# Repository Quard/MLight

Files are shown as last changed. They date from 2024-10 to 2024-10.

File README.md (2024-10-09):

# MLight

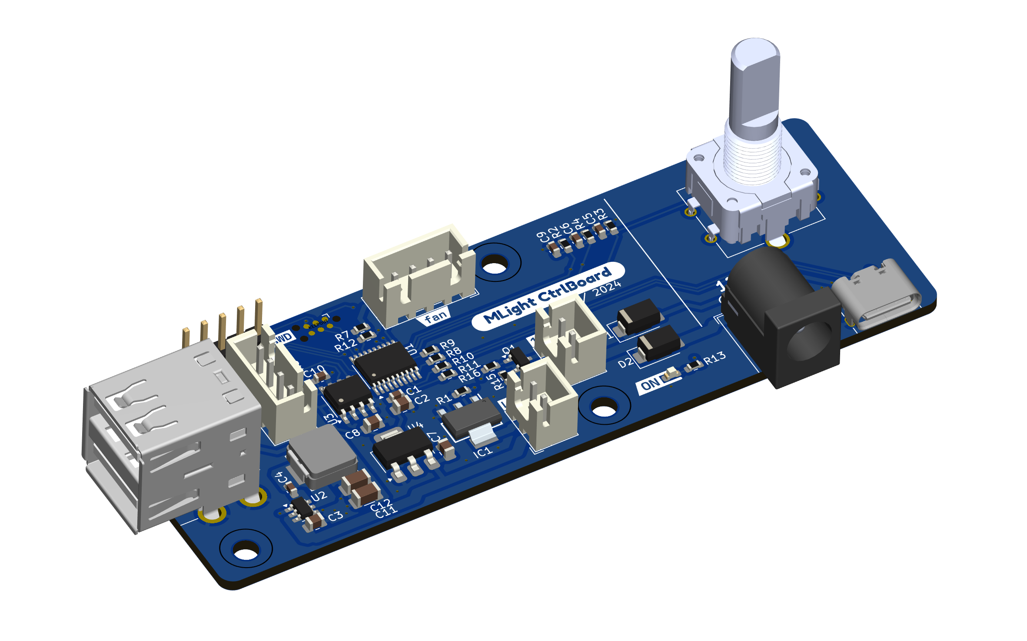
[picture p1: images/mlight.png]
MLight Control Board


MLight is a compact, all-in-one control board designed to manage auxiliary tools for soldering equipment. It was primarily developed for an affordable Chinese digital microscope, aiming to reduce the number of power cords and to integrate lighting for the microscope. Additionally, it can control the fan of a basic DIY fume extractor, built using a PC fan and an aquarium coal filter, and provide power to a small external HDMI display for the microscope.

Features of the Control Board:

* Capable of being powered by an external DC 12V source or a QuickChange USB source.
* Bypasses power to the microscope only when the voltage is at 12V.
* Custom ring light with PWM (Pulse Width Modulation) brightness control.
* The PWM for the light is configurable at frequencies of 1 kHz, 4 kHz, 8 kHz, or 16 kHz to prevent image distortion from the microscope.
* Provides a 12V output for PC fan with PWM speed control support for the DIY fume extractor.
* Features a USB output of 1.5A for powering an external HDMI display.
* Includes an OLED display and encoder for easy control.
* Equipped with external EEPROM memory for storing and restoring settings.

[A brief demonstration video of the system in operation.](https://youtube.com/shorts/ih5DoEOJhLI)

## Controls

| Action | Description |
|---|---|
| Encoder short press | Switch between fan and light |
| Encoder rotate | Change the value of current selected element |
| Encoder long press | Disable/enable fan and light |
| Encoder rotate pressed | Change the light PWM frequency |

## Project parts

### Firmware

The `firmware` folder includes an STM32CubeIDE CMake project, with all source code developed using CMSIS.

### Control Board

The KiCad project is located in the `hardware/control_board` directory. It includes a BOM file in the project root and an interactive BOM (iBOM) in the `bom` folder to facilitate assembly.

### Ring Light

The same structure applies to the Ring Light project, with its root located in the `hardware/ring_light` directory. It also contains a BOM file in the project root and an interactive BOM (iBOM) in the `bom` folder to assist with assembly.

### 3d

The `3d` folder contains STL files and Fusion 360 source files for the brackets used to mount the control board and ring light onto a microscope stand.

## Display elements

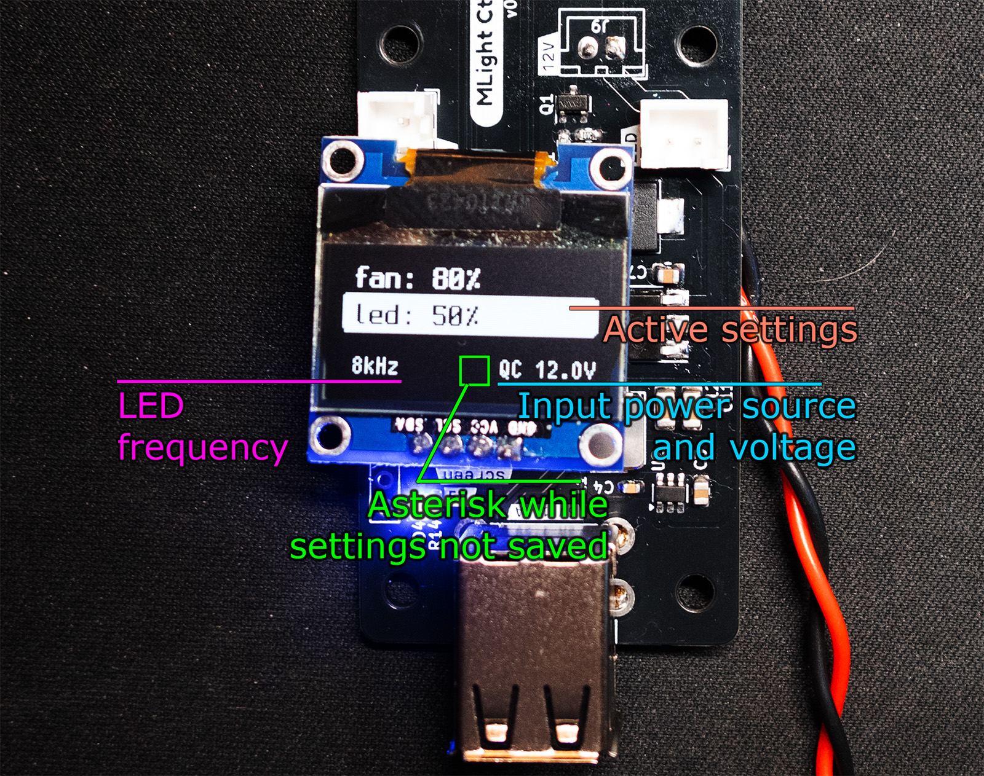
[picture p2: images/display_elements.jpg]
MLight Control board - display elements


## Components block diagram

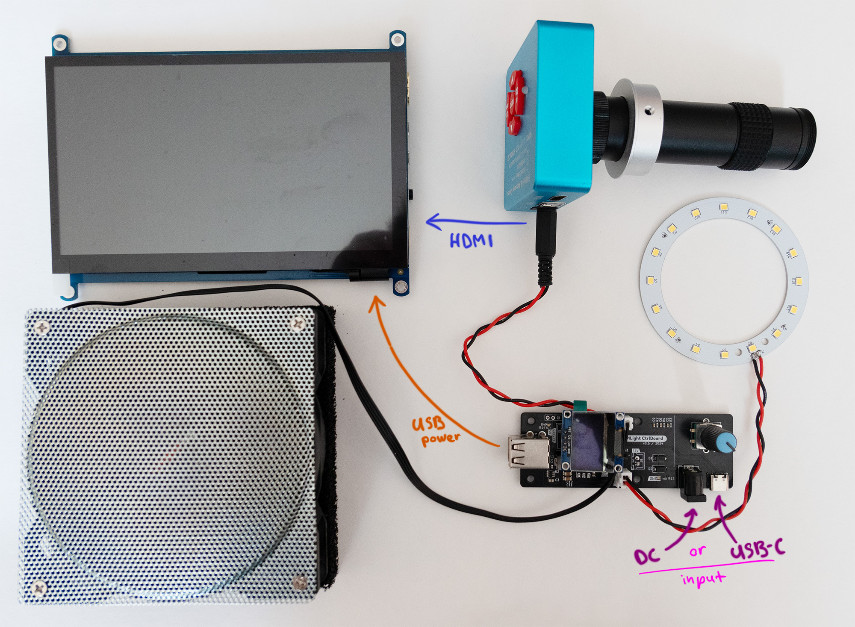
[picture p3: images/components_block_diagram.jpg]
MLight components block diagram


## BOM

### Control Board

|Reference|Value|Qty|Manufacturer Part Number|LCSC|MOUSER|
|---|-----|---|---|----|---|
|C1,C4,C10|100nF|3|CL10B104KB8NNNC|C1591|187-CL10B104KB8NNNC |
|C2|4.7uF|1|CL21A475KAQNNNE|C1779|187-CL21A475KAQNNNE |
|C3,C7,C8|10uF|3|CL21A106KOQNNNE|C1713|187-CL21A106KOQNNNE |
|C5,C6,C9|10nF|3|CL10B103JB8NNNC|C7248|187-CL10B103JB8NNNC |
|C11,C12|22uF|2|CL31A226KAHNNNE|C12891|187-CL31A226KAHNNNE |
|D1,D2|B340|2|B340A-13-F|C85098|621-B340A-F|
|D3|LED|1|150060BS75000|C84266|710-150060BS75000|
|D4|LED|1|150060RS75000|C84263|710-150060RS75000|
|IC1|FZT1049ATA|1|FZT1049ATA|C73835|522-FZT1049ATA|
|J1|USB_A_Stacked|1| 67298-4090|C908455|538-67298-4090|
|J3|Light|1||C158012||
|J4|Fan|1|47053-3000|C19795120|538-47053-3000|
|J5|OLED SSD1306|1||||
|J7|USB_C_Receptacle_USB2.0|1|GSB1C211110DS1HR|C709357|523-GSB1C211110DS1HR|
|J8|Barrel_Jack|1|KLDHCX-0202-BP-LT|C720558|806-KLDHCX0202BPLT|
|J9|Conn_01x02|1||C158012||
|L1|4.7uH|1|IHLP2525CZER4R7M01|C553961|70-IHLP2525CZER4R7M1|
|Q1|AO3400A|1|AO3400A|C20917|942-IRLML6344TRPBF|
|R1,R2,R3,R4,R5,R6,R8,R10,R15|10k|9|RC0603FR-0710KL|C98220|603-RC0603FR-0710KL|
|R7|180k|1|RC0603FR-07180KL|C123419|603-RC0603FR-07180KL|
|R9,R11|2.2k|2|RC0603FR-072K2L|C114662|603-RC0603FR-072K2L|
|R12|33k|1|RC0603FR-0733KL|C126359|603-RC0603FR-0733KL|
|R13,R16|1k|2|RC0603FR-071KL|C22548|603-RC0603FR-071KL|
|R14|1.8k|1|RC0603FR-071K8L|C185354|603-RC0603FR-071K8L|
|SW4|RotaryEncoder_Switch|1|C18164805|652-PEC12R-4220F-S24|PEC12R-4220F-S0024|
|U1|STM32G030F6Px|1|STM32G030F6P6TR|C529330|511-STM32G030F6P6TR|
|U2|AP63205WU|1|AP63205WU-7|C2071056|621-AP63205WU-7|
|U3|M24C02-WMN|1|M24C02-RMN6TP|C83836|511-M24C02-RMN6TP|
|U4|NCP1117-3.3_SOT223|1|NCP1117ST33T3G|C26537|863-NCP1117ST33T3G|

### Ring Light

|Reference|Value|Qty|Manufacturer Part Number|LCSC|MOUSER|
|---|-----|---|---|----|---|
|D1,D2,D3,D4,D5,D6,D7,D8,D9,D10,D11,D12,D13,D14,D15,D16|LED|16|JE2835AWT-R-H40EA0000-N0000001|C5220767|941-JE2835AWTH40EAN|
|R1,R2,R3,R4|0|4|RC0603JR-070RL|C95177|603-RC0603JR-070RL|

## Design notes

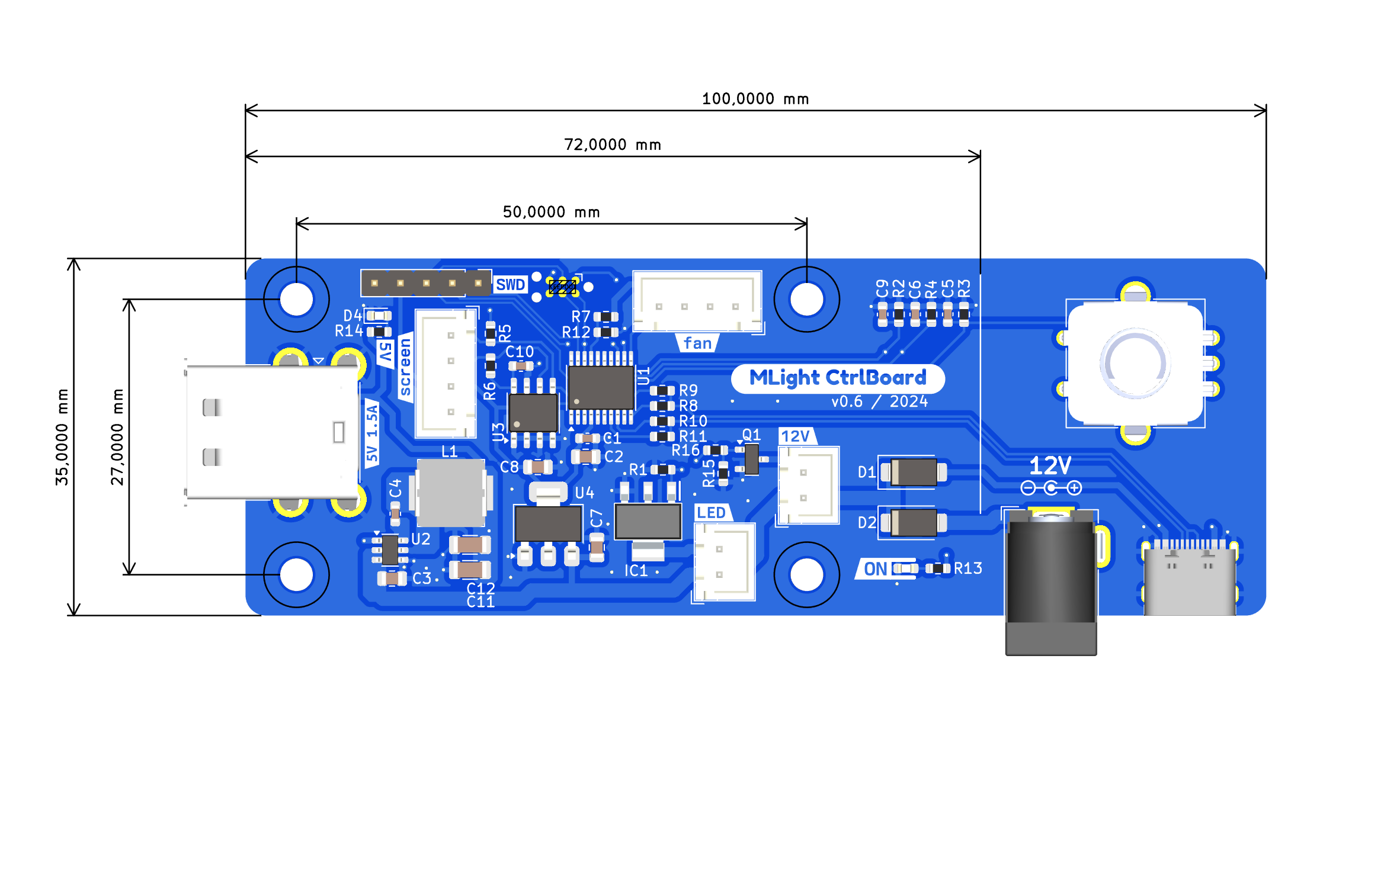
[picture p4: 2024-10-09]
images/control_board.png

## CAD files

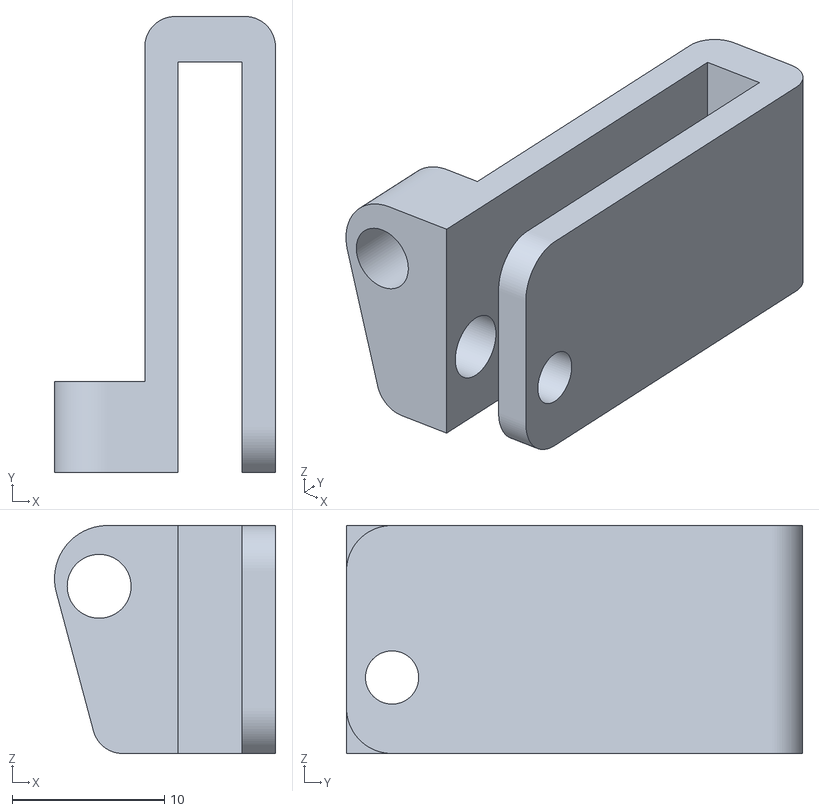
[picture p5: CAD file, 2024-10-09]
3d/Right Light Mount.stl
14.5 x 30.0 x 15.0

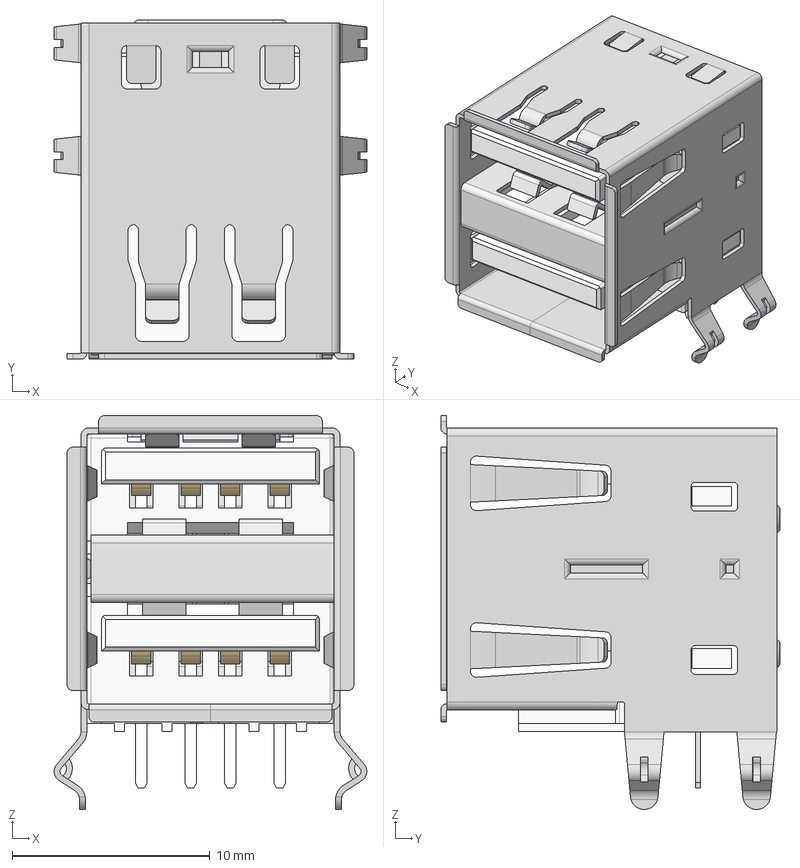
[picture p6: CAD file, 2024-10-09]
hardware/_symbols/3d/USB-A-Stacked.stp
15.8 x 17.1 x 19.9 mm

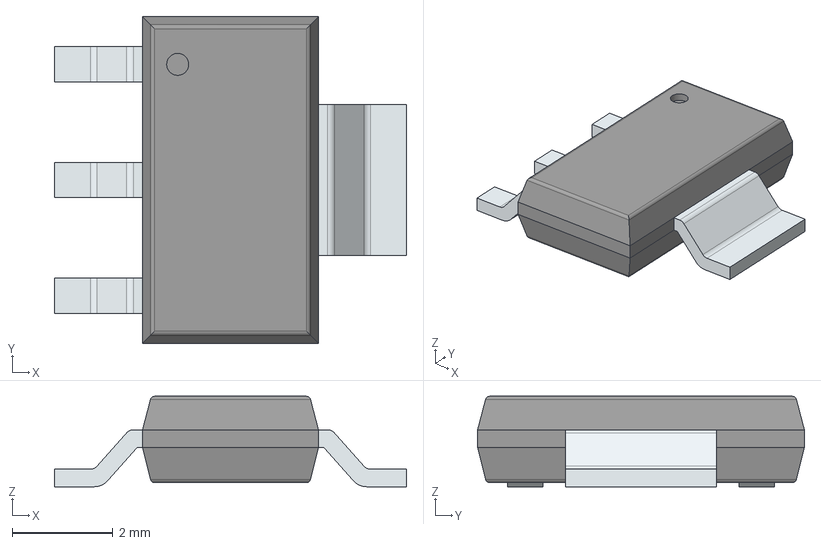
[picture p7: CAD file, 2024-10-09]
hardware/_symbols/FZT1049ATA/FZT1049ATA.stp
7.00 x 6.50 x 1.80 mm
PinsArrayL
FilletPinR

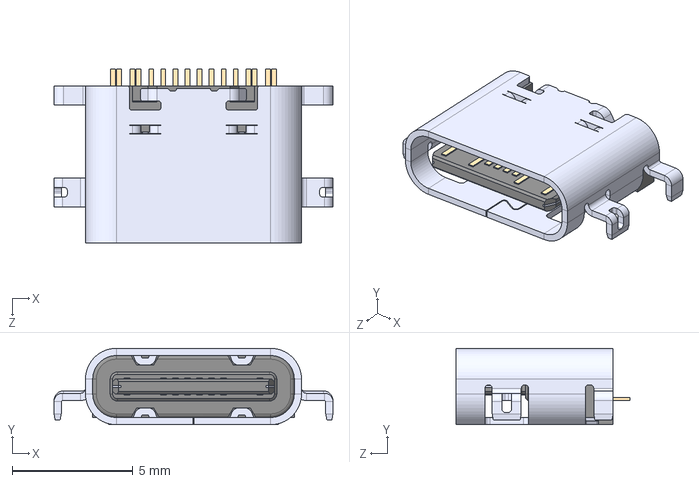
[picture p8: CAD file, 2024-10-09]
hardware/_symbols/USB4505-03-0-A_REVA/USB4505-03-0-A_REVA.step
11.5 x 3.16 x 7.20 mm

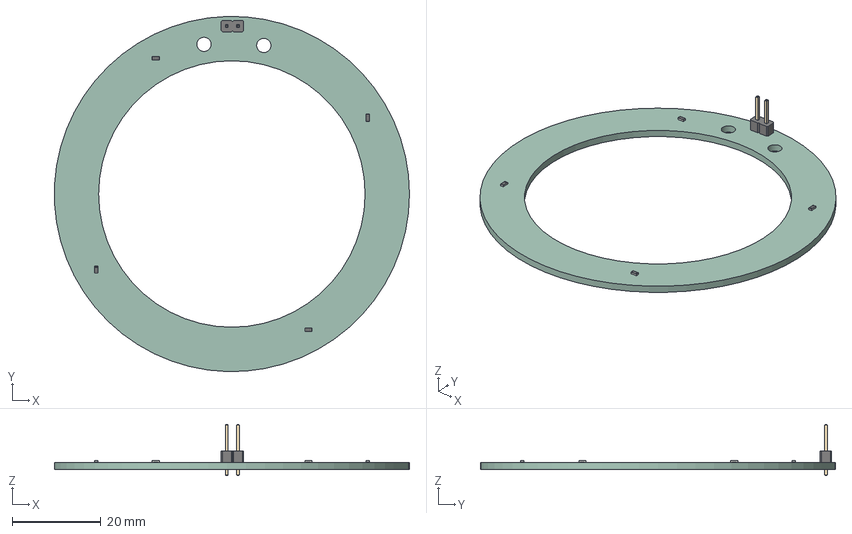
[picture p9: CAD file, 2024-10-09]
hardware/ring_light/ring_light.step
79.9 x 80.0 x 11.5 mm
R_0603_1608Metric x 4
PinHeader_1x02_P254mm_Vertical
ring_light_PCB

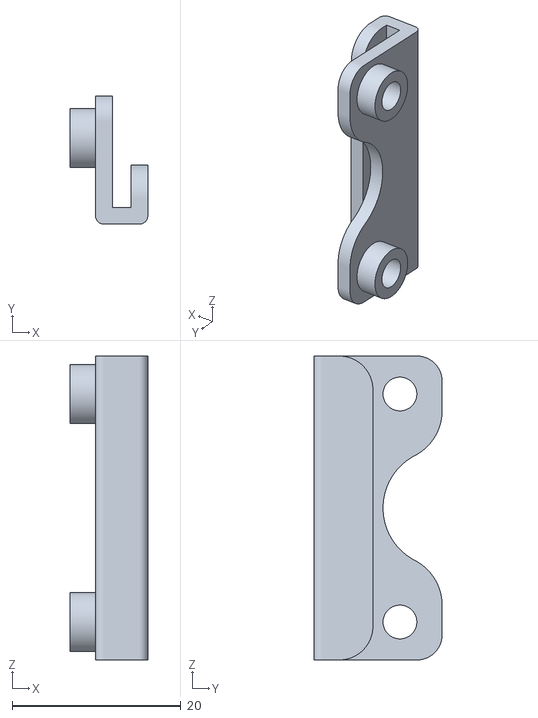
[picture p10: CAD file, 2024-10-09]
3d/Control Board Mount 2.stl
9.20 x 15.2 x 36.0

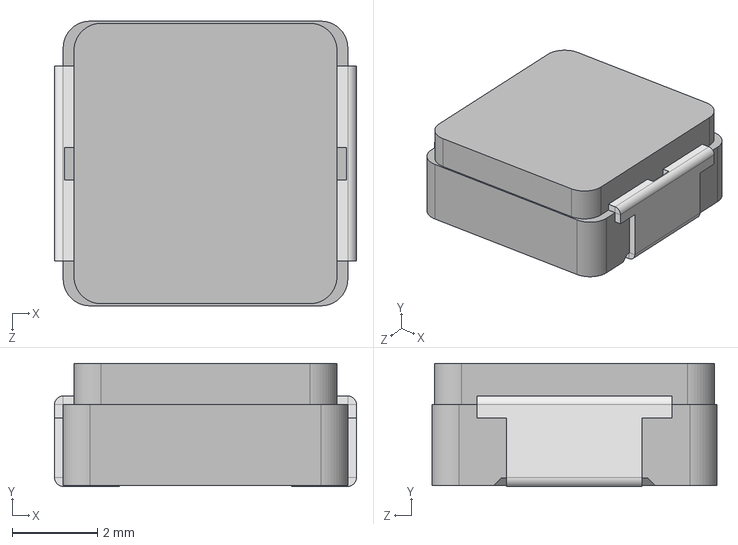
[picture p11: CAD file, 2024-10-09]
hardware/_symbols/3d/IHLP2525CZER4R7M01.stp
7.08 x 2.88 x 6.67 mm

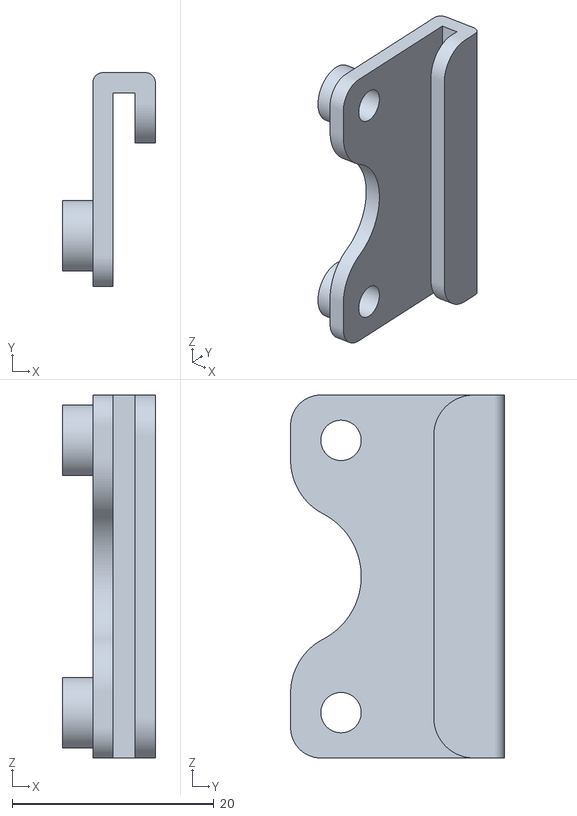
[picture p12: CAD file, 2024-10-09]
3d/Control Board Mount 1.stl
9.20 x 21.2 x 36.0

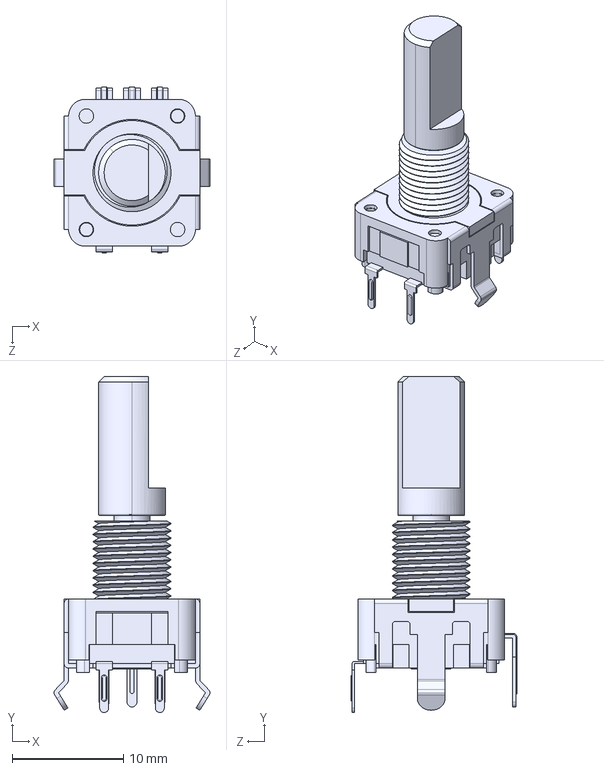
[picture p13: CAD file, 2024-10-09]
hardware/_symbols/3d/PEC11H-4220K-S0024.stp
14.0 x 30.2 x 14.9 mm

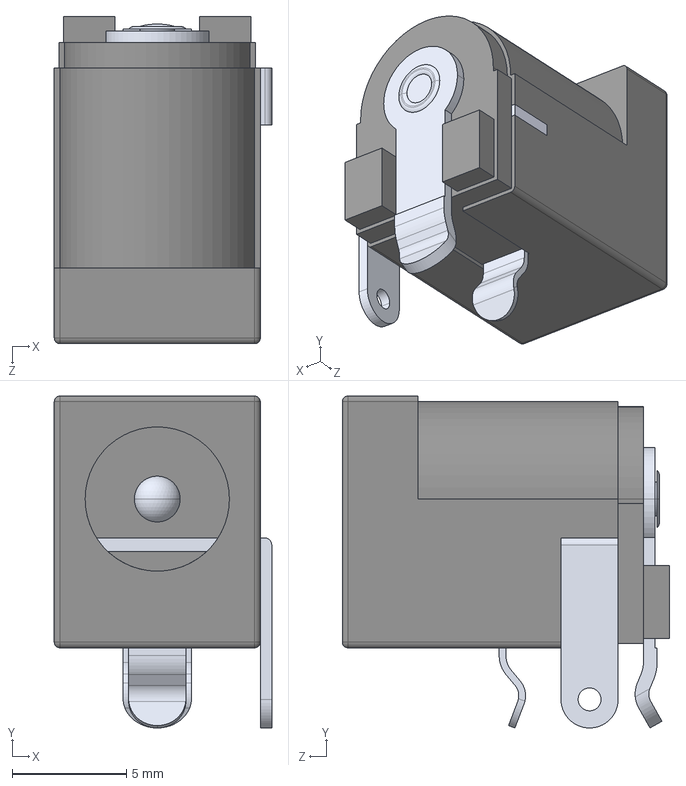
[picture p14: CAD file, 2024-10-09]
hardware/_symbols/3d/DCJ200-10-A-K1-K.stp
9.50 x 14.5 x 14.3 mm

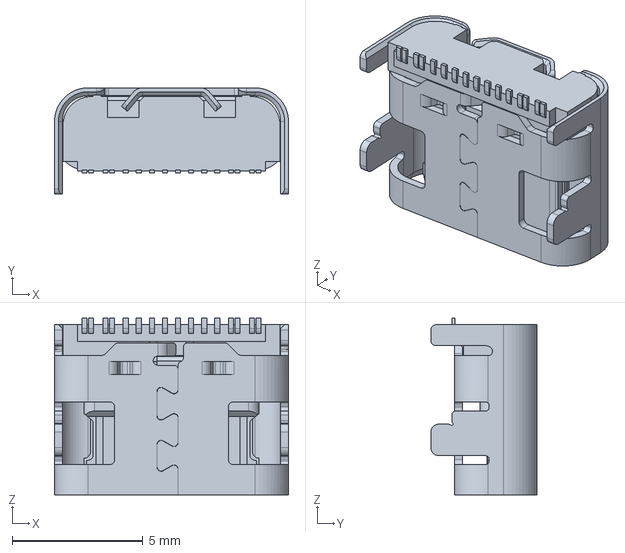
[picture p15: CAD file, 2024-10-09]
hardware/_symbols/3d/USB-C.stp
8.94 x 4.06 x 6.75 mm

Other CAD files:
3d/MLight mount for Eakins Microscope.f3z

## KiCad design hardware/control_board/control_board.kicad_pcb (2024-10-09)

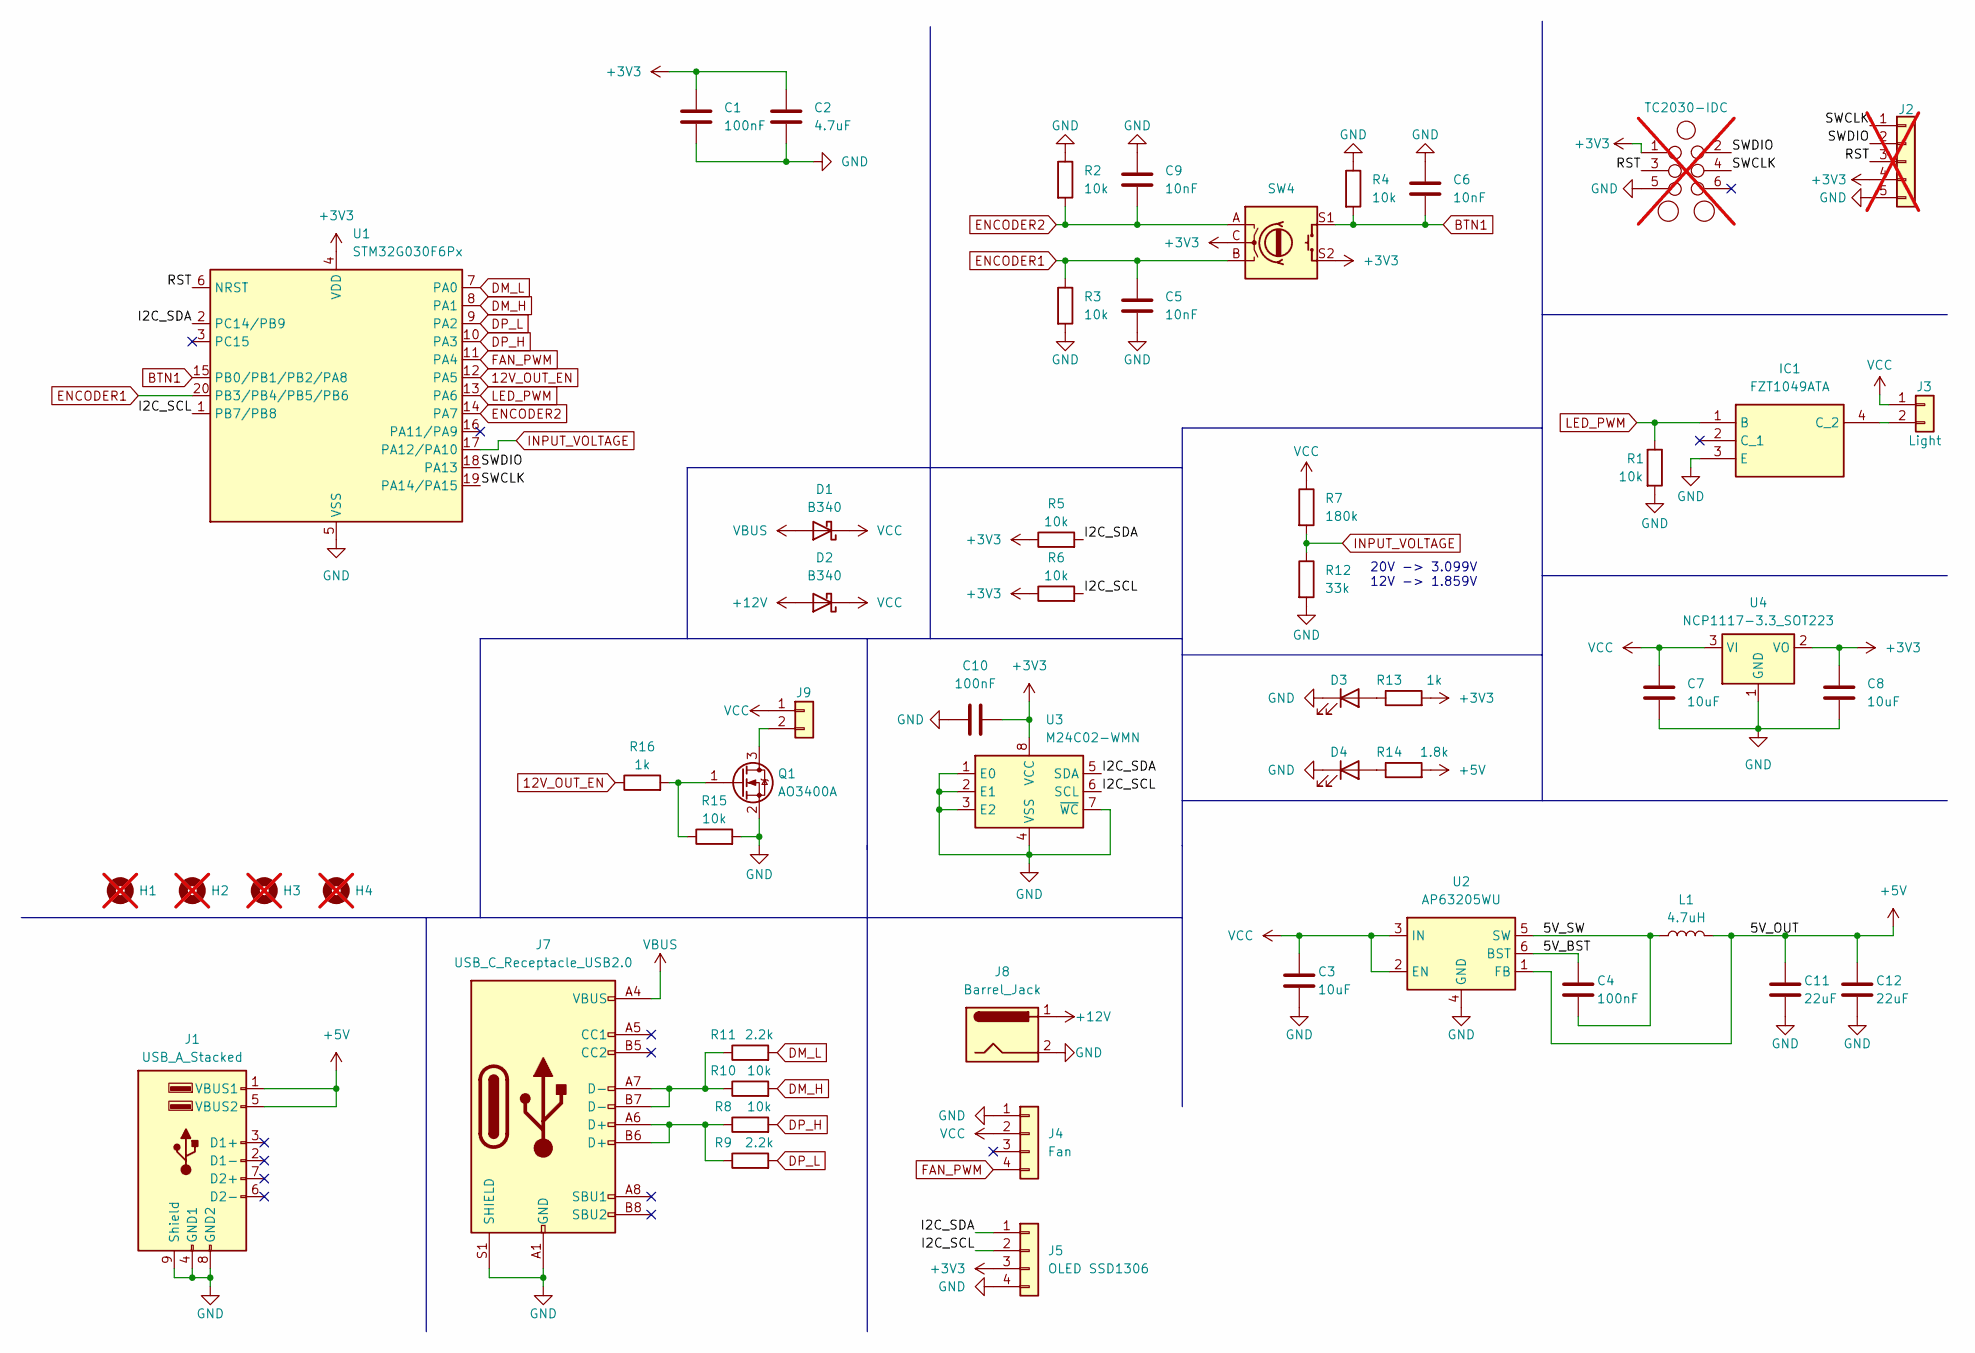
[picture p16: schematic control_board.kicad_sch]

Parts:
C1, C4, C10: 100nF; C_0603_1608Metric; Manufacturer_Part_Number CL10B104KB8NNNC; LCSC C1591
C2: 4.7uF; C_0805_2012Metric; Manufacturer_Part_Number CL21A475KAQNNNE; LCSC C1779
C3, C7, C8: 10uF; C_0805_2012Metric; Manufacturer_Part_Number CL21A106KOQNNNE; LCSC C1713
C5, C6, C9: 10nF; C_0603_1608Metric; Manufacturer_Part_Number CL10B103JB8NNNC; LCSC C7248
C11, C12: 22uF; C_1206_3216Metric; Manufacturer_Part_Number CL31A226KAHNNNE; LCSC C12891
D1, D2: B340; D_SMA; Manufacturer_Part_Number B340A-13-F; LCSC C85098
D3: LED; LED_0603_1608Metric; Manufacturer_Part_Number 150060BS75000; LCSC C84266
D4: LED; LED_0603_1608Metric; Manufacturer_Part_Number 150060RS75000; LCSC C84263
H1, H2, H3, H4: MountingHole; MountingHole_3.2mm_M3; not fitted
IC1: FZT1049ATA; SOT230P700X180-4N; Manufacturer_Part_Number FZT1049ATA; Mouser Part Number 522-FZT1049ATA
J1: USB_A_Stacked; USB_A_CUI_UJ2-ADH-TH_Horizontal_Stacked; Manufacturer_Part_Number 67298-4090; LCSC C908455
J2: Conn_01x05; PinHeader_1x05_P2.54mm_Vertical; not fitted
J3: Light; JST_XH_B2B-XH-A_1x02_P2.50mm_Vertical; LCSC C158012
J4: Fan; JST_XH_B4B-XH-A_1x04_P2.50mm_Vertical; Manufacturer_Part_Number 47053-3000; LCSC C19795120
J5: OLED SSD1306; JST_XH_B4B-XH-A_1x04_P2.50mm_Vertical
J6: TC2030-IDC; Tag-Connect_TC2030-IDC-NL_2x03_P1.27mm_Vertical; not fitted
J7: USB_C_Receptacle_USB2.0; USB_C_Receptacle_Palconn_UTC16-G; Manufacturer_Part_Number GSB1C211110DS1HR; LCSC C709357
J8: Barrel_Jack; BarrelJack_GCT_DCJ200-10-A_Horizontal; Manufacturer_Part_Number KLDHCX-0202-BP-LT; LCSC C720558
J9: Conn_01x02; JST_XH_B2B-XH-A_1x02_P2.50mm_Vertical; LCSC C158012
L1: 4.7uH; L_Vishay_IHLP-2525; Manufacturer_Part_Number IHLP2525CZER4R7M01; LCSC C553961
Q1: AO3400A; SOT-23; Manufacturer_Part_Number AO3400A; LCSC C20917
R1, R2, R3, R4, R5, R6, R8, R10, R15: 10k; R_0603_1608Metric; Manufacturer_Part_Number RC0603FR-0710KL; LCSC C98220
R7: 180k; R_0603_1608Metric; Manufacturer_Part_Number RC0603FR-07180KL; LCSC C123419
R9, R11: 2.2k; R_0603_1608Metric; Manufacturer_Part_Number RC0603FR-072K2L; LCSC C114662
R12: 33k; R_0603_1608Metric; Manufacturer_Part_Number RC0603FR-0733KL; LCSC C126359
R13, R16: 1k; R_0603_1608Metric; Manufacturer_Part_Number RC0603FR-071KL; LCSC C22548
R14: 1.8k; R_0603_1608Metric; Manufacturer_Part_Number RC0603FR-071K8L; LCSC C185354
SW4: RotaryEncoder_Switch; RotaryEncoder_Bourns_Vertical_PEC12R-3x17F-Sxxxx; Manufacturer_Part_Number 652-PEC12R-4220F-S24; LCSC C18164805
U1: STM32G030F6Px; TSSOP-20_4.4x6.5mm_P0.65mm; Manufacturer_Part_Number STM32G030F6P6TR; LCSC C529330
U2: AP63205WU; TSOT-23-6; Manufacturer_Part_Number AP63205WU-7; LCSC C2071056
U3: M24C02-WMN; SOIC-8_3.9x4.9mm_P1.27mm; Manufacturer_Part_Number M24C02-RMN6TP; LCSC C83836
U4: NCP1117-3.3_SOT223; SOT-223-3_TabPin2; Manufacturer_Part_Number NCP1117ST33T3G; LCSC C26537

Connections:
12V_OUT_EN: R16.1, U1.12 (PA5)
+3V3: C1.1, C2.1, C8.1, C10.2, J2.4, J5.3, J6.1, R5.1, R6.1, R13.2, SW4.C, SW4.S2, U1.4 (VDD), U3.8 (VCC), U4.2 (VO)
+5V: C11.1, C12.1, J1.1 (VBUS1), J1.5 (VBUS2), L1.2, R14.2, U2.1 (FB)
+12V: D2.2 (A), J8.1
/5V_BST: C4.1, U2.6 (BST)
/5V_SW: C4.2, L1.1, U2.5 (SW)
/I2C_SCL: J5.2, R6.2, U1.1 (PB7/PB8), U3.6 (SCL)
/I2C_SDA: J5.1, R5.2, U1.2 (PC14/PB9), U3.5 (SDA)
/RST: J2.3, J6.3, U1.6 (NRST)
/SWCLK: J2.1, J6.4, U1.19 (PA14/PA15)
/SWDIO: J2.2, J6.2, U1.18 (PA13)
BTN1: C6.2, R4.2, SW4.S1, U1.15 (PB0/PB1/PB2/PA8)
DM_H: R10.2, U1.8 (PA1)
DM_L: R11.2, U1.7 (PA0)
DP_H: R8.2, U1.10 (PA3)
DP_L: R9.2, U1.9 (PA2)
ENCODER1: C5.1, R3.1, SW4.B, U1.20 (PB3/PB4/PB5/PB6)
ENCODER2: C9.2, R2.2, SW4.A, U1.14 (PA7)
FAN_PWM: J4.4, U1.11 (PA4)
GND: C1.2, C2.2, C3.2, C5.2, C6.1, C7.2, C8.2, C9.1, C10.1, C11.2, C12.2, D3.1 (K), D4.1 (K), IC1.3 (E), J1.4 (GND1), J1.8 (GND2), J1.9 (Shield), J2.5, J4.1, J5.4, J6.5, J7.A1 (GND), J7.A12 (GND), J7.B1 (GND), J7.B12 (GND), J7.S1 (SHIELD), J8.2, Q1.2 (S), R1.2, R2.1, R3.2, R4.1, R12.2, R15.2, U1.5 (VSS), U2.4 (GND), U3.1 (E0), U3.2 (E1), U3.3 (E2), U3.4 (VSS), U3.7 (~WC), U4.1 (GND)
INPUT_VOLTAGE: R7.2, R12.1, U1.17 (PA12/PA10)
LED_PWM: IC1.1 (B), R1.1, U1.13 (PA6)
unnamed: D3.2 (A), R13.1
unnamed: D4.2 (A), R14.1
unnamed: IC1.4 (C_2), J3.2
unnamed: J7.A6 (D+), J7.B6 (D+), R8.1, R9.1
unnamed: J7.A7 (D-), J7.B7 (D-), R10.1, R11.1
unnamed: J9.2, Q1.3 (D)
unnamed: Q1.1 (G), R15.1, R16.2
VBUS: D1.2 (A), J7.A4 (VBUS), J7.A9 (VBUS), J7.B4 (VBUS), J7.B9 (VBUS)
VCC: C3.1, C7.1, D1.1 (K), D2.1 (K), J3.1, J4.2, J9.1, R7.1, U2.2 (EN), U2.3 (IN), U4.3 (VI)

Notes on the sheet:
20V -> 3.099V 12V -> 1.859V

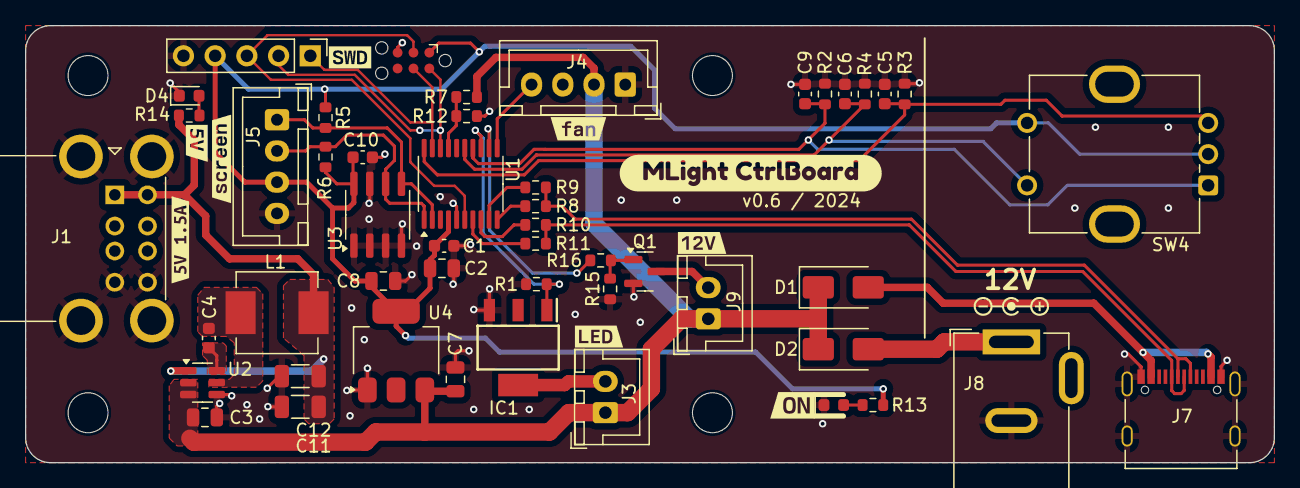
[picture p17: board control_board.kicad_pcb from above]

Board: 2 copper layers, 100.0 x 35.0 mm, 62 parts (0 on the bottom side), 31 nets.

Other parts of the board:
kibuzzard-64DFCA22: G***; kibuzzard-64DFCA22
kibuzzard-64E1B8AF: G***; kibuzzard-64E1B8AF
kibuzzard-64E1B90C: G***; kibuzzard-64E1B90C
kibuzzard-64E666E4: G***; kibuzzard-64E666E4
kibuzzard-65854A39: G***; kibuzzard-65854A39
kibuzzard-6585330A: G***; kibuzzard-6585330A
kibuzzard-6585337F: G***; kibuzzard-6585337F
kibuzzard-65853391: G***; kibuzzard-65853391
kibuzzard-65855076: G***; kibuzzard-65855076

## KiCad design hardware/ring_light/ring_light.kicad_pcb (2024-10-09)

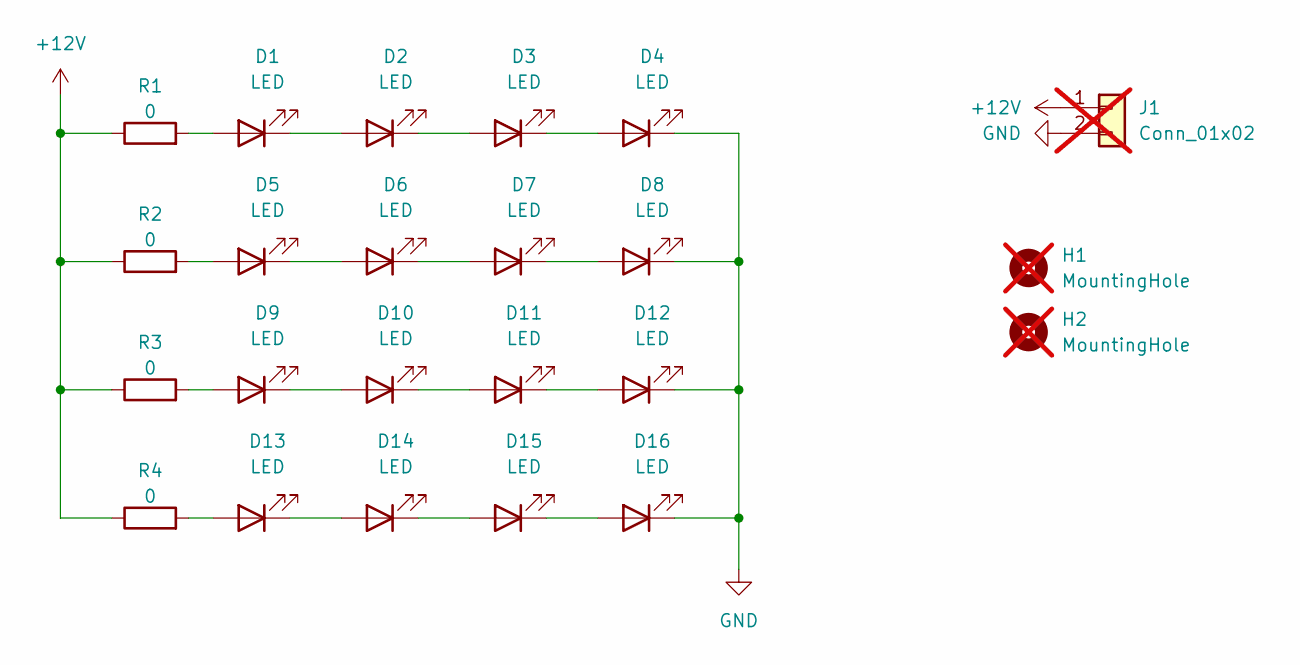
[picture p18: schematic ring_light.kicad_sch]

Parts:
D1, D2, D3, D4, D5, D6, D7, D8, D9, D10, D11, D12, D13, D14, D15, D16: LED; LED_PLCC_2835; Manufacturer Part Number JE2835AWT-R-H40EA0000-N0000001; LCSC C5220767
H1, H2: MountingHole; MountingHole_3.2mm_M3; not fitted
J1: Conn_01x02; PinHeader_1x02_P2.54mm_Vertical; not fitted
R1, R2, R3, R4: 0; R_0603_1608Metric; Manufacturer Part Number RC0603JR-070RL; LCSC C95177

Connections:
+12V: J1.1, R1.1, R2.1, R3.1, R4.1
GND: D4.1 (K), D8.1 (K), D12.1 (K), D16.1 (K), J1.2
unnamed: D1.2 (A), R1.2
unnamed: D1.1 (K), D2.2 (A)
unnamed: D2.1 (K), D3.2 (A)
unnamed: D3.1 (K), D4.2 (A)
unnamed: D5.2 (A), R2.2
unnamed: D5.1 (K), D6.2 (A)
unnamed: D6.1 (K), D7.2 (A)
unnamed: D7.1 (K), D8.2 (A)
unnamed: D9.2 (A), R3.2
unnamed: D9.1 (K), D10.2 (A)
unnamed: D10.1 (K), D11.2 (A)
unnamed: D11.1 (K), D12.2 (A)
unnamed: D13.2 (A), R4.2
unnamed: D13.1 (K), D14.2 (A)
unnamed: D14.1 (K), D15.2 (A)
unnamed: D15.1 (K), D16.2 (A)

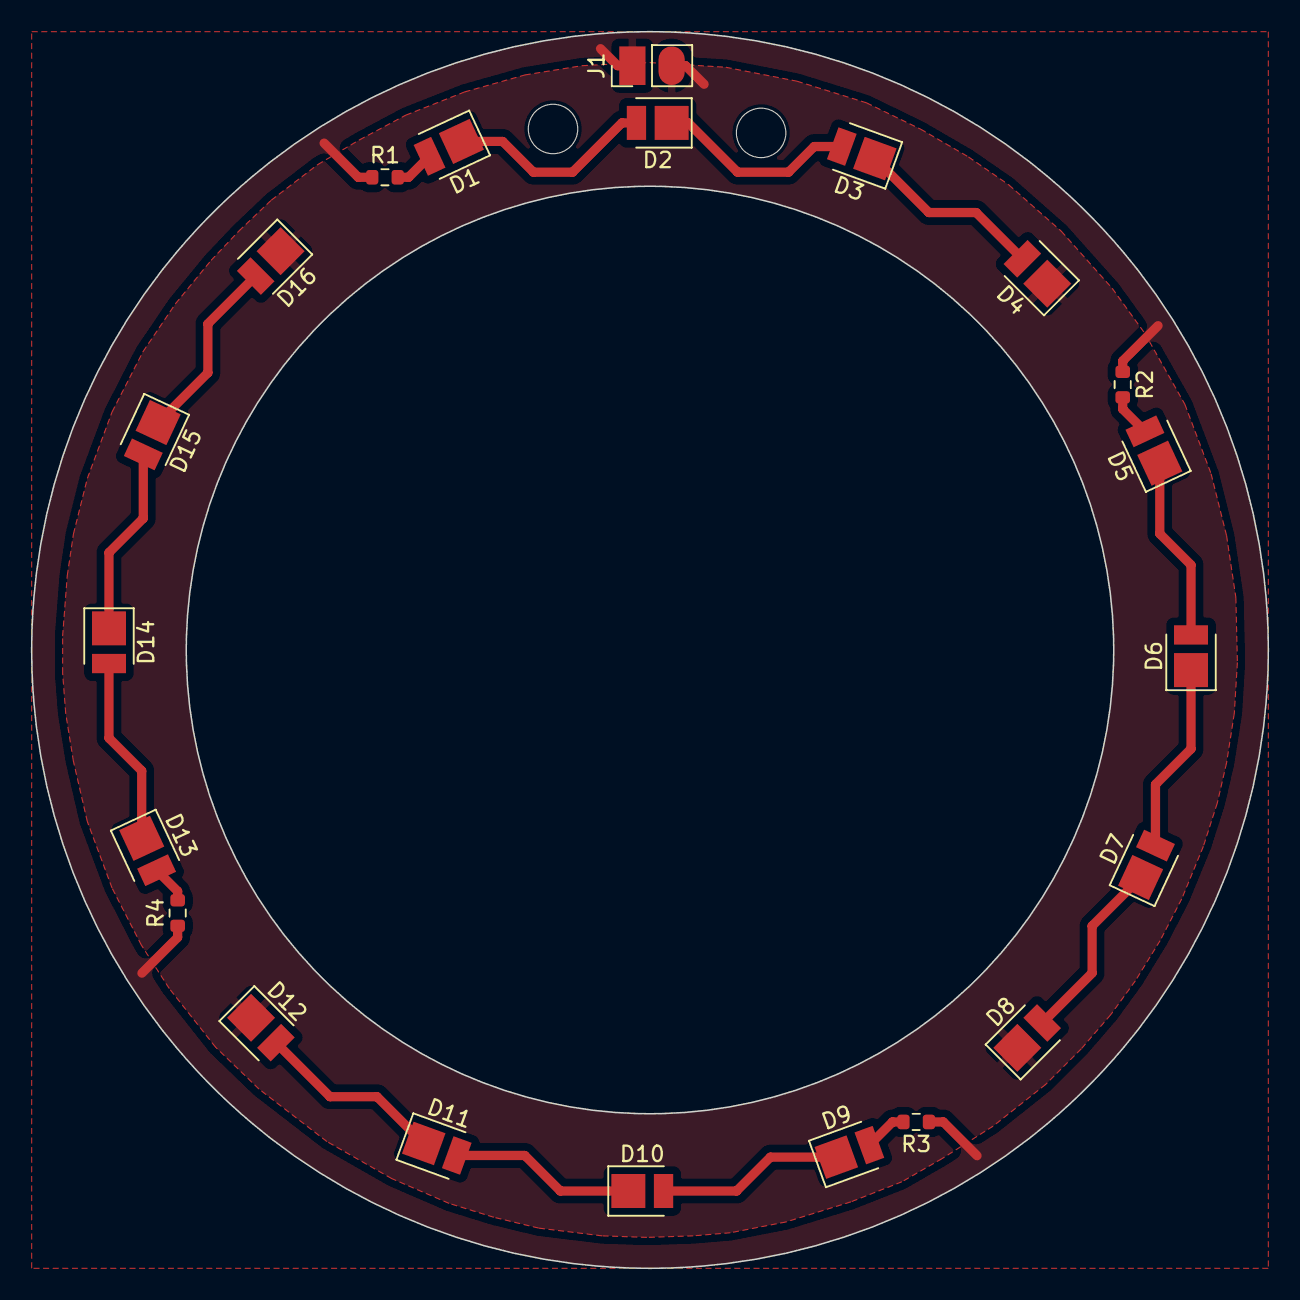
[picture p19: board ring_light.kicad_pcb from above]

Board: 2 copper layers, 80.0 x 80.0 mm, 23 parts (0 on the bottom side), 18 nets.

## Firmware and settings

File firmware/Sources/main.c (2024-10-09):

#include <stdint.h>
#include "stm32g030xx.h"
#include "mlight.h"
#include "utils.h"
#include "peripherals/adc.h"
#include "peripherals/i2c.h"
#include "features/fan.h"
#include "features/backlight.h"
#include "features/ui.h"
#include "features/control.h"
#include "features/mem.h"
#include "features/qc.h"


#define ADC_TO_VOLTS(x)  ((uint8_t)(x / 4095.f * 3.3f * 6.4462f * 10))

void mcu_init(void);

extern volatile int8_t enc_value;
extern volatile uint8_t enc_click;
volatile uint32_t tick;
volatile uint8_t ui_update_event = 1;
volatile uint16_t adc_voltage = 0;

int main(void) {
	qc_t qc;
	mlight_t mlight = {
		.fan_speed=0,
		.led_freq=0,
		.led_brightness=0,
		.voltage=0,
		.voltage_source=0,
		.menu_active=1,
		.state=0
	};

	mcu_init();

	i2c1_init();
	adc_init();
	ui_init();
	mem_read(&mlight);

	fan_init();
	backlight_init();
	control_init();

	while (!adc_voltage);
	mlight.voltage = ADC_TO_VOLTS(adc_voltage);
	if (mlight.voltage > 35 && mlight.voltage < 55) {
		if (qc_init(&qc) == QC_RET_OK) {
			mlight.voltage_source = VOLTAGE_SOURCE_QC;
			qc_set_mode(&qc, QC_MODE_12V);
		}
	}

	delay_ms(1000);

	fan_set_speed(mlight.fan_speed);
	backlight_set_freq(mlight.led_freq);
	backlight_set_brightness(mlight.led_brightness);

	mlight.voltage = ADC_TO_VOLTS(adc_voltage);
	if (mlight.voltage > 110 && mlight.voltage < 130) {
		GPIOA->MODER &= ~(0b11 << 10);
		GPIOA->MODER |= (0b01 << 10);
		GPIOA->ODR |= (1 << 5);
	}

	uint8_t mem_save_counter = 0;
	uint8_t ctrl_res;
	for(;;) {
		ctrl_res = control_update(&mlight);
		if (ctrl_res == CTRL_ACTION_UPDATE) {
			fan_set_speed(mlight.fan_speed);
			backlight_set_freq(mlight.led_freq);
			backlight_set_brightness(mlight.led_brightness);

			mem_save_counter = 50;
			mlight.state |= 1 << STATE_HAS_CHANGES;
		} else if (ctrl_res == CTRL_ACTION_PAUSE) {
			mlight.state ^= 1 << STATE_PAUSE;
			if (mlight.state & (1 << STATE_PAUSE)) {
				fan_set_speed(0);
				backlight_set_brightness(0);
			} else {
				fan_set_speed(mlight.fan_speed);
				backlight_set_brightness(mlight.led_brightness);
			}
		}

		if (ui_update_event) {
			mlight.voltage = ADC_TO_VOLTS(adc_voltage);
			ui_update_event = 0;
			ui_update(&mlight);

			if (mem_save_counter) {
				if (mem_save_counter == 1) {
					mem_save(&mlight);
					mlight.state &= ~(1 << STATE_HAS_CHANGES);
				}
				mem_save_counter--;
			}
		}
	}
}

void mcu_init(void) {
	RCC->IOPENR |= RCC_IOPENR_GPIOAEN | RCC_IOPENR_GPIOBEN;
	SysTick_Config(16000);

	__enable_irq();
}

void SysTick_Handler(void) {
	tick++;
	if (tick % 25 == 0) ui_update_event = 1;
}

void ADC_IRQHandler(void) {
	adc_voltage = ADC1->DR;
}

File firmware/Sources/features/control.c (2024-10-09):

#include "features/control.h"


void _ctrl_encoder_init(void);
void _ctrl_button_init(void);
void _ctrl_update_value(uint8_t *value, uint8_t step);

extern volatile uint32_t tick;
volatile int8_t enc_value = 0;
volatile uint32_t enc_btn = 0;
volatile uint8_t enc_btn_press = 0;
uint8_t enc_btn_skip_press = 0;

void control_init(void) {
	_ctrl_encoder_init();
	_ctrl_button_init();
}

void _ctrl_encoder_init(void) {
	// TIM3 Encoder mode
	// PA7, PB3
	GPIOA->MODER &= ~(0b11 << 14);
	GPIOA->MODER |= (0b10 << 14);
	GPIOA->OSPEEDR |= 0b10 << 14;
	GPIOA->AFR[0] |= (0b0001 << 28);
	GPIOB->MODER &= ~(0b11 << 8);
	GPIOB->MODER |= (0b10 << 8);
	GPIOB->OSPEEDR |= 0b10 << 8;
	GPIOB->AFR[0] |= (0b0001 << 16);

	RCC->APBENR1 |= RCC_APBENR1_TIM3EN;
	TIM3->CR1 = TIM_CR1_ARPE;
	TIM3->CCMR1 = (0b01 << TIM_CCMR1_CC1S_Pos) | (0b01 << TIM_CCMR1_CC2S_Pos);
	TIM3->SMCR = 0b0011;
	TIM3->CCER = TIM_CCER_CC1E | TIM_CCER_CC2E | TIM_CCER_CC1P;
	TIM3->DIER = TIM_DIER_CC1IE | TIM_DIER_CC2IE;
	TIM3->CR1 |= TIM_CR1_CEN;

	NVIC_EnableIRQ(TIM3_IRQn);
}

void _ctrl_button_init(void) {
	// PB0
	RCC->APBENR2 |= RCC_APBENR2_SYSCFGEN;
	GPIOB->MODER &= ~(0b11 << 0);

	EXTI->RTSR1 |= 1;
	EXTI->FTSR1 |= 1;
	EXTI->EXTICR[0] |= 0x01 << EXTI_EXTICR1_EXTI0_Pos;
	EXTI->IMR1 |= 1;

	NVIC_EnableIRQ(EXTI0_1_IRQn);
}

uint8_t control_update(mlight_t *mlight) {
	if (enc_value) {
		if (enc_btn) {
			enc_btn_skip_press = 1;
			if (enc_value > 0 && mlight->led_freq < LED_FREQ_OPTIONS - 1) {
				mlight->led_freq++;
			} else if (enc_value < 0 && mlight->led_freq > 0) {
				mlight->led_freq--;
			}
		} else {
			if (mlight->menu_active == 1) {
				_ctrl_update_value(&(mlight->led_brightness), 1);
			} else {
				_ctrl_update_value(&(mlight->fan_speed), 5);
			}
		}

		enc_value = 0;
		return CTRL_ACTION_UPDATE;
	} else if (enc_btn_press == BTN_SHORT_PRESS) {
		mlight->menu_active = mlight->menu_active == 1 ? 0 : 1;
		enc_btn_press = 0;
	} else if (enc_btn_press == BTN_LONG_PRESS) {
		enc_btn_press = 0;
		return CTRL_ACTION_PAUSE;
	}

	return 0;
}

void _ctrl_update_value(uint8_t *value, uint8_t step) {
	if (enc_value > 0 && *value + step <= 100) {
		*value += step;
	} else if (enc_value < 0 && *value - step >= 0) {
		*value -= step;
	}
}

void TIM3_IRQHandler(void) {
	if (TIM3->CR1 & TIM_CR1_DIR) {
		enc_value = 1;
	} else {
		enc_value = -1;
	}
	TIM3->SR &= ~(TIM_SR_CC1IF | TIM_SR_CC2IF);
}

void EXTI0_1_IRQHandler(void) {
	if (EXTI->RPR1 & 1) {
		enc_btn = tick;
		EXTI->RPR1 |= 1;
	} else if (EXTI->FPR1 & 1) {
		if (!enc_btn_skip_press) {
			uint32_t time = tick - enc_btn;

			if (time < BTN_SHORT_PRESS_TIME) {
				enc_btn_press = BTN_SHORT_PRESS;
			} else if (time > BTN_LONG_PRESS_TIME && time < BTN_MAX_PRESS_TIME) {
				enc_btn_press = BTN_LONG_PRESS;
			} else {
				enc_btn_press = 0;
			}
		}

		enc_btn = 0;
		enc_btn_skip_press = 0;
		EXTI->FPR1 |= 1;
	}
}

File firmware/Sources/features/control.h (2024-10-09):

#ifndef __FEATURES_CONTROL_H__
#define __FEATURES_CONTROL_H__

#include "stm32g030xx.h"
#include "mlight.h"

#define BTN_SHORT_PRESS  1
#define BTN_LONG_PRESS   2
#define BTN_SHORT_PRESS_TIME  300
#define BTN_LONG_PRESS_TIME   900
#define BTN_MAX_PRESS_TIME    3000

#define CTRL_ACTION_UPDATE 1
#define CTRL_ACTION_PAUSE  2

void control_init(void);
uint8_t control_update(mlight_t *mlight);

#endif /* __FEATURES_CONTROL_H__ */
